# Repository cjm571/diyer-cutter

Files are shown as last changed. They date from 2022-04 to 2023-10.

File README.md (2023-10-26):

# Build Process

## Dev Container

### Windows 11

#### Prerequisites

* Ubuntu under WSL2
* Install and configure [USBIPD-WIN](https://learn.microsoft.com/en-us/windows/wsl/connect-usb#install-the-usbipd-win-project) in Ubuntu

#### Procedure

0. Connect BBC micro:bit to PC via USB
1. Run `tools/setup.ps1` to attach the micro:bit to WSL (see [this](https://github.com/dorssel/usbipd-win/wiki/WSL-support) if error occurs)
2. Execute `Dev Containers: Reopen in Container`
3. Open a terminal in the container and execute `cargo run`

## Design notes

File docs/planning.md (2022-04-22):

# Requirements
## Hardware
* The device shall be able to feed small-gauge wire to a cutting head.
* The device shall have a safety covering over the cutting head.
* The device shall be able to cut small-gauge wire.
* The device shall be able to cut small-gauge wire with an accuracy of ±1/16in
* The device shall have a single power on/off switch.
* The device shall display information and user prompts on a 16x2 LCD.
* The device shall accept user input from a 3x4 matrix keypad.
* The device shall drop cut wire into a receptacle.
* The device shall use a BBC micro:bit V2 as a system controller.
* The device shall enter a safe "fail state" if any errors are encountered.

## Software
* The software shall allow the user to select the desired size of cut wire.
* The software shall allow the user to select the number of wires to cut.
* The software shall be able to detect when a spool of wire has run out.

# Architecture
## State Machine
The micro:bit must maintain a set of states and transitions in order to provide a straightforward experience.

## Initialization
Upon receiving power, the peripheral devices attached to the micro:bit must be initialized (and optionally tested). This module will be responsible for performing these initialization sequences.

## Input Parsing
Inputs from peripheral devices must be received and parsed in order to determine the status of the system and perform to user specification.

## Motor Driver(s)
The motor(s) must be driven to user specification.

# Design
## Statechart
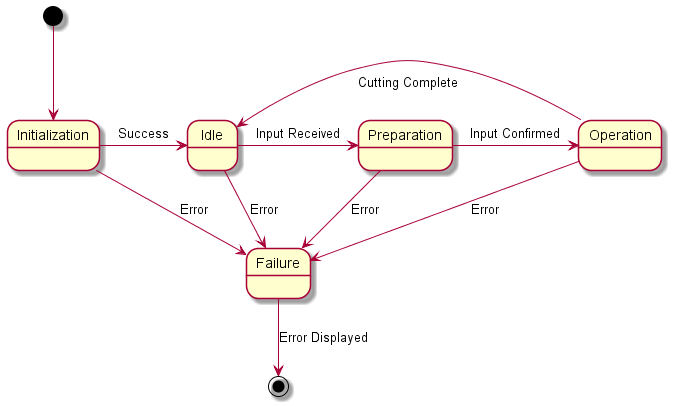
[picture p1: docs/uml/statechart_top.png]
Statechart


## Initialization
Upon power-up, the micro:bit will take the following sequence of actions:

1. Verify communications with LCD
2. Verify communications with keypad
3. Verify communications with motor(s) 
4. Enter Idle state

## Idle
A largely quiescent state where the micro:bit will sit idle until the user begins providing input via the keypad.

## Preparation
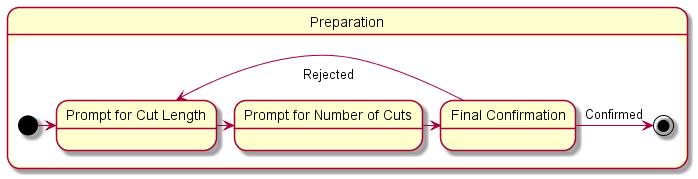
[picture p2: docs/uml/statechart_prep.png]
Statechart

This is the input-collection state. A series of prompts will be presented to the user on the LCD to determine the parameters of the cuts that should be made. The user will respond to the prompt and press "`#`" to confirm the response; "`*`" can be used as a backspace button. The prompts will be:

1. Cut length
```
0123456789012345
CUT LENGTH (in):
-> _
```
2. Number of cuts
```
0123456789012345
NUMBER OF CUTS:
-> _
```
3. Final confirmation
```
0123456789012345
XXin x YYYY
OK? (#=Y, *=N) _
```

If the user chooses "`*`" for "No" at the final prompt, the micro:bit will return to the first prompt. If the inputs are confirmed, the micro:bit will progress to the Operation stage.

## Operation
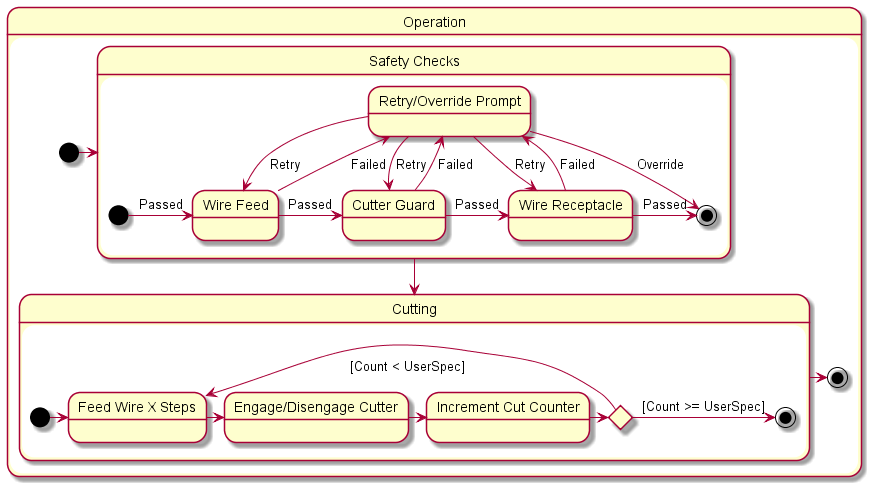
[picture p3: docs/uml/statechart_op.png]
Statechart

This is the cutting stage. Before cutting can begin, safety sensors are checked to ensure that the system is ready for safe operation. If any safety sensors are not in the right state, the micro:bit will prompt the user to check the associated safety device. The user may enter an override code to bypass the sensors in the event of an undetected error preventing the sensor from reporting correctly.

Safety checks include:

* Wire is properly fed
* Cutter guard is in place
* Cut wire receptacle is in place

Once safety checks have passed (or been overridden) the micro:bit will perform the following sequence of actions

1. Command feed stepper motor to advance the appropriate number of steps to reach the user-specified cut length.
2. Command cutter servo motor to engage the cutting head for one cycle
3. Increment cut counter
4. Repeat steps 1-3 until user-specified cut count is reached

Upon successful completion of all cuts, the micro:bit will return the system to the Idle state, where the user may begin the process again with more wire.

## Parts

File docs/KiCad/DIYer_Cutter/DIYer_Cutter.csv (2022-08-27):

Source: | D:\Documents\KiCad\6.0\projects\DIYer_Cutter\DIYer_Cutter.kicad_sch
Date: | 6/24/2022 9:31:56 PM
Tool: | Eeschema (6.0.5)
Generator: | C:\Program Files\KiCad\6.0\bin\scripting\plugins/bom_csv_grouped_by_value.py
Component Count: | 74
Individual Components:
Item | Qty | Reference(s) | Value | LibPart | Footprint | Datasheet
 |  | DS1 | WC1602A | Display_Character:WC1602A | Display:WC1602A | http://www.wincomlcd.com/pdf/WC1602A-SFYLYHTC06.pdf
 |  | M1 | Stepper_Motor_bipolar | Motor:Stepper_Motor_bipolar | Connector_PinHeader_2.54mm:PinHeader_1x04_P2.54mm_Vertical | http://www.infineon.com/dgdl/Application-Note-TLE8110EE_driving_UniPolarStepperMotor_V1.1.pdf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
 |  | M2 | Motor_Servo | Motor:Motor_Servo | Connector_PinHeader_2.54mm:PinHeader_1x03_P2.54mm_Horizontal | http://forums.parallax.com/uploads/attachments/46831/74481.png
 |  | R1 | R_Small_US | Device:R_Small_US |  | ~
 |  | R2 | R_Small_US | Device:R_Small_US |  | ~
 |  | R3 | R_Small_US | Device:R_Small_US |  | ~
 |  | R4 | R_Small_US | Device:R_Small_US |  | ~
 |  | R5 | R_Small_US | Device:R_Small_US |  | ~
 |  | R6 | R_Small_US | Device:R_Small_US |  | ~
 |  | R7 | R_Small_US | Device:R_Small_US |  | ~
 |  | R8 | R_Small_US | Device:R_Small_US |  | ~
 |  | R9 | R_Small_US | Device:R_Small_US |  | ~
 |  | R10 | R_Small_US | Device:R_Small_US |  | ~
 |  | R11 | R_Small_US | Device:R_Small_US |  | ~
 |  | R12 | R_Small_US | Device:R_Small_US |  | ~
 |  | R13 | R_Small_US | Device:R_Small_US |  | ~
 |  | R14 | R_Small_US | Device:R_Small_US |  | ~
 |  | R15 | R_Small_US | Device:R_Small_US |  | ~
 |  | R16 | R_Small_US | Device:R_Small_US |  | ~
 |  | R17 | R_Small_US | Device:R_Small_US |  | ~
 |  | R18 | R_Small_US | Device:R_Small_US |  | ~
 |  | R19 | R_Small_US | Device:R_Small_US |  | ~
 |  | R20 | R_Small_US | Device:R_Small_US |  | ~
 |  | R21 | R_Small_US | Device:R_Small_US |  | ~
 |  | R22 | R_Small_US | Device:R_Small_US |  | ~
 |  | R23 | R_Small_US | Device:R_Small_US |  | ~
 |  | R24 | R_Small_US | Device:R_Small_US |  | ~
 |  | R25 | R_Small_US | Device:R_Small_US |  | ~
 |  | R26 | R_Small_US | Device:R_Small_US |  | ~
 |  | R27 | R_Small_US | Device:R_Small_US |  | ~
 |  | R28 | R_Small_US | Device:R_Small_US |  | ~
 |  | R29 | R_Small_US | Device:R_Small_US |  | ~
 |  | R30 | R_Small_US | Device:R_Small_US |  | ~
 |  | R31 | R_Small_US | Device:R_Small_US |  | ~
 |  | R32 | R_Small_US | Device:R_Small_US |  | ~
 |  | R33 | R_Small_US | Device:R_Small_US |  | ~
 |  | R34 | R_Small_US | Device:R_Small_US |  | ~
 |  | R35 | R_Small_US | Device:R_Small_US |  | ~
 |  | R36 | R_Small_US | Device:R_Small_US |  | ~
 |  | R37 | R_Small_US | Device:R_Small_US |  | ~
 |  | R38 | R_Small_US | Device:R_Small_US |  | ~
 |  | R39 | R_Small_US | Device:R_Small_US |  | ~
 |  | R40 | R_Small_US | Device:R_Small_US |  | ~
 |  | R41 | R_Small_US | Device:R_Small_US |  | ~
 |  | R42 | R_Small_US | Device:R_Small_US |  | ~
 |  | R43 | R_Small_US | Device:R_Small_US |  | ~
 |  | R44 | R_Small_US | Device:R_Small_US |  | ~
 |  | R45 | R_Small_US | Device:R_Small_US |  | ~
 |  | R46 | R_Small_US | Device:R_Small_US |  | ~
 |  | R47 | R_Small_US | Device:R_Small_US |  | ~
 |  | R48 | R_Small_US | Device:R_Small_US |  | ~
 |  | R49 | R_Small_US | Device:R_Small_US |  | ~
 |  | R50 | R_Small_US | Device:R_Small_US |  | ~
 |  | R51 | R_Small_US | Device:R_Small_US |  | ~
 |  | R52 | R_Small_US | Device:R_Small_US |  | ~
 |  | R53 | R_Small_US | Device:R_Small_US |  | ~
 |  | R54 | R_Small_US | Device:R_Small_US |  | ~
 |  | R55 | R_Small_US | Device:R_Small_US |  | ~
 |  | R56 | R_Small_US | Device:R_Small_US |  | ~
 |  | R57 | R_Small_US | Device:R_Small_US |  | ~
 |  | R58 | R_Small_US | Device:R_Small_US |  | ~
 |  | R59 | R_Small_US | Device:R_Small_US |  | ~
 |  | R60 | R_Small_US | Device:R_Small_US |  | ~
 |  | R61 | R_Small_US | Device:R_Small_US |  | ~
 |  | R62 | R_Small_US | Device:R_Small_US |  | ~
 |  | SW1 | SW_Push | Switch:SW_Push |  | ~
 |  | U1 | micro:bit | DIYer_Cutter:BBC_micro{colon}bit_Breakout_Board
 |  | U2 | MCP23008-xP | Interface_Expansion:MCP23008-xP | Package_DIP:DIP-18_W7.62mm | http://ww1.microchip.com/downloads/en/DeviceDoc/MCP23008-MCP23S08-Data-Sheet-20001919F.pdf
 |  | U3 | MCP23008-xP | Interface_Expansion:MCP23008-xP | Package_DIP:DIP-18_W7.62mm | http://ww1.microchip.com/downloads/en/DeviceDoc/MCP23008-MCP23S08-Data-Sheet-20001919F.pdf
 |  | U4 | keypad_3x4_matrix | DIYer_Cutter:keypad_3x4_matrix
 |  | U5 | MCP23008-xP | Interface_Expansion:MCP23008-xP | Package_DIP:DIP-18_W7.62mm | http://ww1.microchip.com/downloads/en/DeviceDoc/MCP23008-MCP23S08-Data-Sheet-20001919F.pdf
 |  | U6 | easy_stepper_driver | DIYer_Cutter:easy_stepper_driver
 |  | U7 | 74HCT125 | DIYer_Cutter:74HCT125 |  | http://www.ti.com/lit/ds/symlink/sn74hct125.pdf
 |  | U8 | 74HC245 | 74xx:74HC245 | Package_DIP:DIP-20_W7.62mm | http://www.ti.com/lit/gpn/sn74HC245
Collated Components:
Item | Qty | Reference(s) | Value | LibPart | Footprint | Datasheet
1 | 1 | DS1 | WC1602A | Display_Character:WC1602A | Display:WC1602A | http://www.wincomlcd.com/pdf/WC1602A-SFYLYHTC06.pdf
2 | 1 | M1 | Stepper_Motor_bipolar | Motor:Stepper_Motor_bipolar | Connector_PinHeader_2.54mm:PinHeader_1x04_P2.54mm_Vertical | http://www.infineon.com/dgdl/Application-Note-TLE8110EE_driving_UniPolarStepperMotor_V1.1.pdf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
3 | 1 | M2 | Motor_Servo | Motor:Motor_Servo | Connector_PinHeader_2.54mm:PinHeader_1x03_P2.54mm_Horizontal | http://forums.parallax.com/uploads/attachments/46831/74481.png
4 | 62 | R1, R2, R3, R4, R5, R6, R7, R8, R9, R10, R11, R12, R13, R14, R15, R16, R17, R18, R19, R20, R21, R22, R23, R24, R25, R26, R27, R28, R29, R30, R31, R32, R33, R34, R35, R36, R37, R38, R39, R40, R41, R42, R43, R44, R45, R46, R47, R48, R49, R50, R51, R52, R53, R54, R55, R56, R57, R58, R59, R60, R61, R62 | R_Small_US | Device:R_Small_US |  | ~
5 | 1 | SW1 | SW_Push | Switch:SW_Push |  | ~
6 | 1 | U1 | micro:bit | DIYer_Cutter:BBC_micro{colon}bit_Breakout_Board
7 | 3 | U2, U3, U5 | MCP23008-xP | Interface_Expansion:MCP23008-xP | Package_DIP:DIP-18_W7.62mm | http://ww1.microchip.com/downloads/en/DeviceDoc/MCP23008-MCP23S08-Data-Sheet-20001919F.pdf
8 | 1 | U4 | keypad_3x4_matrix | DIYer_Cutter:keypad_3x4_matrix
9 | 1 | U6 | easy_stepper_driver | DIYer_Cutter:easy_stepper_driver
10 | 1 | U7 | 74HCT125 | DIYer_Cutter:74HCT125 |  | http://www.ti.com/lit/ds/symlink/sn74hct125.pdf
11 | 1 | U8 | 74HC245 | 74xx:74HC245 | Package_DIP:DIP-20_W7.62mm | http://www.ti.com/lit/gpn/sn74HC245

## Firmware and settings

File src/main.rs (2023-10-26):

/*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
\* * * * * * * * * * * * * * * * * * * * * * * * * * * * * * * * * * * * * * */

#![no_main]
#![no_std]

use core::cell::RefCell;

use cortex_m::{
    interrupt::{self as cortex_interrupt, Mutex},
    peripheral::NVIC,
};

use microbit::{
    hal::{gpio::Level, prelude::*, timer, twim, Timer, Twim},
    pac::{interrupt, Interrupt, PWM0, TIMER0, TIMER1, TWIM0},
    Board,
};

mod i2c;
use crate::i2c::{
    keypad::{self, Key},
    lcd1602,
};

mod servo;
use servo::Servo;

///////////////////////////////////////////////////////////////////////////////
//  Named Constants
///////////////////////////////////////////////////////////////////////////////

const ONE_SECOND_IN_MHZ: u32 = 1000000;
const GREETING_DUR_IN_MS: u32 = 2500;

// Cap input to 5 digits for ease of implementation
const MAX_INPUT_CHARS: usize = 5;

const CUT_CYCLE_TIME_MS: u32 = 1500;
const WIRE_FEED_TIME_MS: u32 = 3000;

///////////////////////////////////////////////////////////////////////////////
//  Shared Peripheral Handles
///////////////////////////////////////////////////////////////////////////////

static TIMER0_HANDLE: Mutex<RefCell<Option<Timer<TIMER0>>>> = Mutex::new(RefCell::new(None));
static TIMER1_HANDLE: Mutex<RefCell<Option<Timer<TIMER1>>>> = Mutex::new(RefCell::new(None));
static I2C0_HANDLE: Mutex<RefCell<Option<Twim<TWIM0>>>> = Mutex::new(RefCell::new(None));
static CUTTER_HANDLE: Mutex<RefCell<Option<Servo<PWM0>>>> = Mutex::new(RefCell::new(None));

///////////////////////////////////////////////////////////////////////////////
//  Tasks
///////////////////////////////////////////////////////////////////////////////

#[cortex_m_rt::entry]
fn main() -> ! {
    defmt::println!("Hello, world!");

    init();

    defmt::println!("Initialization Complete!");

    idle();
}

fn init() {
    // Take ownership of the full board
    let board = Board::take().unwrap();

    // Hold various chips in reset/output-disabled
    let i2c_reset_pin = board.pins.p1_02.into_push_pull_output(Level::Low); // P16
    let mut lcd_lvshift_oe_pin = board.pins.p0_12.into_push_pull_output(Level::High); // P12

    // Instantiate a timer
    let timer0 = init_1s_timer(board.TIMER0);

    // Initialize a 1-second timer
    let timer1 = init_1s_timer(board.TIMER1);
    cortex_interrupt::free(|cs| TIMER1_HANDLE.borrow(cs).replace(Some(timer1)));

    // Initialize the TWIM0 (I2C) controller
    let mut i2c0 = i2c::init(
        board.TWIM0,
        board.i2c_external,
        &mut i2c_reset_pin.degrade(),
    );

    // Initialize LCD Display and display greeting
    defmt::println!("Enabling power to LCD Display...");
    lcd1602::power_on(&mut i2c0);

    defmt::println!("Enabling output on LCD Level Shifter...");
    lcd_lvshift_oe_pin.set_low().unwrap();

    defmt::println!("Initializing LCD Display...");
    cortex_interrupt::free(|cs| {
        let mut local_timer1_handle_ref = TIMER1_HANDLE.borrow(cs).borrow_mut();
        let local_timer1_handle = local_timer1_handle_ref.as_mut().unwrap();
        lcd1602::init(local_timer1_handle, &mut i2c0);
    });

    defmt::println!("Initializing 3x4 Matrix Keypad...");
    keypad::init(&mut i2c0);

    defmt::println!("Initializing Cutter Servo...");
    let pwm_output_pin = board.pins.p0_09.into_push_pull_output(Level::Low).degrade();
    let cutter = Servo::new(board.PWM0, microbit::hal::pwm::Channel::C0, pwm_output_pin);

    // Store the peripheral handles in RefCells, so interrupts and main thread can use them
    cortex_interrupt::free(|cs| TIMER0_HANDLE.borrow(cs).replace(Some(timer0)));
    cortex_interrupt::free(|cs| I2C0_HANDLE.borrow(cs).replace(Some(i2c0)));
    cortex_interrupt::free(|cs| CUTTER_HANDLE.borrow(cs).replace(Some(cutter)));
}

fn idle() -> ! {
    cortex_interrupt::free(|cs| {
        // Capture shared peripheral handles locally
        let mut local_timer0_handle_ref = TIMER0_HANDLE.borrow(cs).borrow_mut();
        let timer0 = local_timer0_handle_ref.as_mut().unwrap();
        let mut local_i2c0_handle_ref = I2C0_HANDLE.borrow(cs).borrow_mut();
        let i2c0 = local_i2c0_handle_ref.as_mut().unwrap();
        let mut local_cutter_handle_ref = CUTTER_HANDLE.borrow(cs).borrow_mut();
        let cutter = local_cutter_handle_ref.as_mut().unwrap();

        // Display greeting
        lcd1602::display_greeting(timer0, i2c0);
        timer0.delay_ms(GREETING_DUR_IN_MS);

        // Input Loop
        let mut cut_length;
        let mut num_cuts;
        loop {
            // Prompt user for Cut Length
            defmt::println!("Prompting user for Cut Length...");
            cut_length = get_user_parameter("CUT LENGTH (in):\n-> ", timer0, i2c0);
            defmt::println!("User accepted Cut Length of {}", cut_length);

            // Prompt user for Number of Cuts
            defmt::println!("Prompting user for Number of Cuts...");
            num_cuts = get_user_parameter("NUMBER OF CUTS:\n-> ", timer0, i2c0);
            defmt::println!("User accepted Number of Cuts of {}", num_cuts);

            // Present final confirmation
            defmt::println!("Presenting final confirmation to user...");
            if !final_confirmation(cut_length, num_cuts, timer0, i2c0) {
                // User rejected confirmation, return to top of input loop
                defmt::println!("User rejected confirmation");
                continue;
            } else {
                // User accepted confirmation, break out of input loop
                defmt::println!("User accepted confirmation");
                break;
            }
        }

        // Cutting Loop
        lcd1602::clear_display(timer0, i2c0);
        lcd1602::write_string("Cutting...\n00000 / ", timer0, i2c0);
        lcd1602::write_u32(num_cuts, timer0, i2c0);
        lcd1602::shift_cursor(lcd1602::Direction::Left, 8, timer0, i2c0);
        for i in 1..=num_cuts {
            // Update LCD
            lcd1602::backspace(5, timer0, i2c0);
            lcd1602::write_u32(i, timer0, i2c0);

            // Perform a single cut
            cutter.set_duty(12.0);
            timer0.delay_ms(CUT_CYCLE_TIME_MS);
            cutter.set_duty(3.0);

            // Allow time for wire feed
            timer0.delay_ms(WIRE_FEED_TIME_MS);
        }

        lcd1602::clear_display(timer0, i2c0);
        lcd1602::write_string("Finished Cutting\nWoohoo! <3", timer0, i2c0);
    });

    defmt::println!("Entering Idle loop");
    loop {
        cortex_interrupt::free(|cs| {
            // Capture shared peripheral handles locally
            let mut local_timer0_handle_ref = TIMER0_HANDLE.borrow(cs).borrow_mut();
            let timer0 = local_timer0_handle_ref.as_mut().unwrap();
            timer0.delay_ms(500_u32);
        });
    }
}

///////////////////////////////////////////////////////////////////////////////
//  Helper Functions
///////////////////////////////////////////////////////////////////////////////

fn init_1s_timer<T: timer::Instance>(instance: T) -> Timer<T> {
    // Create the Timer object
    let mut timer_device = Timer::new(instance);

    // Stop and clear the timer before configuring it
    timer_device.task_stop().write(|w| w.tasks_stop().trigger());
    timer_device
        .task_clear()
        .write(|w| w.tasks_clear().trigger());

    // [2022-05-15] Don't need to set prescaler or bit mode because microbit crate
    // currently hardcodes these to 1MHz and 32bit mode

    // Enable and unmask the interrupt
    timer_device.enable_interrupt();
    unsafe {
        NVIC::unmask(Interrupt::TIMER1);
    }

    // [2022-05-15] microbit crate currently does not expose the SHORTS register space
    // Cannot configure timer to auto-reset on reaching the specified tick count

    // Start the timer
    timer_device.start(ONE_SECOND_IN_MHZ);

    timer_device
}

fn get_user_parameter<T: timer::Instance, U: twim::Instance>(
    prompt: &str,
    timer: &mut Timer<T>,
    i2c: &mut Twim<U>,
) -> u32 {
    lcd1602::clear_display(timer, i2c);
    lcd1602::write_string(prompt, timer, i2c);

    let mut user_input: [&str; 12] = [""; 12];
    let mut user_input_idx = 0;
    loop {
        if let Some(pressed_key) = keypad::scan(timer, i2c) {
            // Check for '#', which will parse and accept the input
            if pressed_key == Key::Pound {
                let mut parsed_input = 0;
                for (order_of_magnitude, parsed_value) in user_input
                    .iter()
                    .rev()
                    .flat_map(|v| v.parse::<u32>())
                    .enumerate()
                {
                    parsed_input += parsed_value * u32::pow(10, order_of_magnitude as u32);
                }

                return parsed_input;
            }
            // Check for '*', which acts as a backspace key
            if pressed_key == Key::Star {
                //OPT: Beep if input is empty?
                // Don't allow backspace if input is empty
                if user_input_idx > 0 {
                    lcd1602::backspace(1, timer, i2c);
                    user_input_idx -= 1;
                    user_input[user_input_idx] = "";
                }

                continue;
            }

            //OPT: Beep if input is full?
            // If not at max length, write the key to the LCD and record it in the input array
            if user_input_idx < MAX_INPUT_CHARS {
                lcd1602::write_string(pressed_key.into(), timer, i2c);
                user_input[user_input_idx] = pressed_key.into();
                user_input_idx += 1;
            }
        } else {
            continue;
        }
    }
}

fn final_confirmation<T: timer::Instance, U: twim::Instance>(
    cut_length: u32,
    num_cuts: u32,
    timer: &mut Timer<T>,
    i2c: &mut Twim<U>,
) -> bool {
    lcd1602::clear_display(timer, i2c);
    lcd1602::write_u32(cut_length, timer, i2c);
    lcd1602::write_string("in x ", timer, i2c);
    lcd1602::write_u32(num_cuts, timer, i2c);
    lcd1602::write_string("\nOK? (#=Y, *=N) ", timer, i2c);

    loop {
        if let Some(pressed_key) = keypad::scan(timer, i2c) {
            if pressed_key == Key::Pound {
                // User accepted confirmation
                return true;
            } else if pressed_key == Key::Star {
                // User rejected confirmation
                return false;
            } else {
                continue;
            }
        }
    }
}

///////////////////////////////////////////////////////////////////////////////
//  Interrupt Handlers
///////////////////////////////////////////////////////////////////////////////

#[interrupt]
fn TIMER1() {
    // Clear the timer interrupt flag && restart 1s timer
    cortex_interrupt::free(|cs| {
        let mut local_timer1_handle_ref = TIMER1_HANDLE.borrow(cs).borrow_mut();
        let local_timer1_handle = local_timer1_handle_ref.as_mut().unwrap();
        local_timer1_handle
            .event_compare_cc0()
            .write(|w| w.events_compare().not_generated());

        local_timer1_handle.start(ONE_SECOND_IN_MHZ);
    });
}

///////////////////////////////////////////////////////////////////////////////
//  Embedded Boilerplate
///////////////////////////////////////////////////////////////////////////////

use cortex_m_semihosting::debug;

use defmt_rtt as _; // global logger

use microbit as _; // memory layout

use panic_probe as _;

// same panicking *behavior* as `panic-probe` but doesn't print a panic message
// this prevents the panic message being printed *twice* when `defmt::panic` is invoked
#[defmt::panic_handler]
fn panic() -> ! {
    cortex_m::asm::udf()
}

/// Terminates the application and makes a semihosting-capable debug tool exit
/// with status code 0.
pub fn exit() -> ! {
    loop {
        debug::exit(debug::EXIT_SUCCESS);
    }
}

/// Hardfault handler.
///
/// Terminates the application and makes a semihosting-capable debug tool exit
/// with an error. This seems better than the default, which is to spin in a
/// loop.
#[cortex_m_rt::exception]
unsafe fn HardFault(_frame: &cortex_m_rt::ExceptionFrame) -> ! {
    loop {
        debug::exit(debug::EXIT_FAILURE);
    }
}

// defmt-test 0.3.0 has the limitation that this `#[tests]` attribute can only be used
// once within a crate. the module can be in any file but there can only be at most
// one `#[tests]` module in this library crate
#[cfg(test)]
#[defmt_test::tests]
mod unit_tests {
    use defmt::assert;

    #[test]
    fn it_works() {
        assert!(true)
    }
}

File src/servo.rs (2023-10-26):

/*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
\* * * * * * * * * * * * * * * * * * * * * * * * * * * * * * * * * * * * * * */

use core::fmt::Debug;
use microbit::hal::{
    gpio::{Output, Pin, PushPull},
    pwm,
};

///////////////////////////////////////////////////////////////////////////////
//  Named Constants
///////////////////////////////////////////////////////////////////////////////

const FIFTY_HZ_IN_500KHZ_TICKS: u16 = 10000;
const PWM_ENABLE: u32 = 1;
const TRIGGER_TASK: u32 = 1;
const INFINITY_SAFE_LOOP_CNT: u32 = 2;

const DECODER_CMP_VALUE_MASK: u16 = 0x7FFF;

///////////////////////////////////////////////////////////////////////////////
//  Data Structures
///////////////////////////////////////////////////////////////////////////////

pub struct Servo<T: pwm::Instance> {
    pwm_inst: T,
    _channel: pwm::Channel,
    _output_pin: Pin<Output<PushPull>>,
    common_duty: [u16; 2],
}

///////////////////////////////////////////////////////////////////////////////
//  Object Implementations
///////////////////////////////////////////////////////////////////////////////

impl<T: pwm::Instance> Servo<T> {
    pub fn new(pwm_inst: T, channel: pwm::Channel, output_pin: Pin<Output<PushPull>>) -> Self {
        // Before configuring, trigger TASKS_STOP to ensure a stable reset state
        pwm_inst
            .tasks_stop
            .write(|w| unsafe { w.bits(TRIGGER_TASK) });

        // Set the output pin
        pwm_inst.psel.out[0].write(|w| unsafe { w.bits(output_pin.psel_bits()) });

        // Enable the PWM Generator
        pwm_inst.enable.write(|w| unsafe { w.bits(PWM_ENABLE) });

        // Set the frequency to 50Hz via PRESCALER, COUNTERTOP register
        pwm_inst.prescaler.write(|w| w.prescaler().div_32()); // Divide clock down to 500kHz
        pwm_inst
            .countertop
            .write(|w| unsafe { w.countertop().bits(FIFTY_HZ_IN_500KHZ_TICKS) });

        // Set the duty cycle to 0 (common to all channels due to default DECODER config)
        let common_duty = [0, 0];
        pwm_inst
            .seq0
            .ptr
            .write(|w| unsafe { w.ptr().bits(common_duty.as_ptr() as u32) });
        pwm_inst.seq0.cnt.write(|w| unsafe { w.bits(1) });
        pwm_inst.seq0.refresh.write(|w| unsafe { w.bits(0) });

        // Configure PWM to loop infinitely on common duty cycle sequence by setting loop count > 1
        // and enabling shortcut that will link the LOOPSDONE even and SEQSTART[0]
        pwm_inst
            .loop_
            .write(|w| unsafe { w.bits(INFINITY_SAFE_LOOP_CNT) });
        pwm_inst.shorts.write(|w| w.loopsdone_seqstart0().enabled());

        // Note: The following registers are left untouched as their reset values are already the desired values:
        // MODE, DECODER, SEQ[0].ENDDELAY, SEQ[1].*

        Self {
            pwm_inst,
            _channel: channel,
            _output_pin: output_pin,
            common_duty,
        }
    }

    pub fn set_duty(&mut self, duty: f32) {
        // Set the new duty cycle
        self.common_duty = [
            ((FIFTY_HZ_IN_500KHZ_TICKS as f32 / 100.0) * duty) as u16 | 1 << 15,
            0,
        ];
        self.pwm_inst
            .seq0
            .ptr
            .write(|w| unsafe { w.ptr().bits(self.common_duty.as_ptr() as u32) });

        // Start the sequence again
        self.pwm_inst.tasks_seqstart[0].write(|w| unsafe { w.bits(TRIGGER_TASK) });
    }
}

impl<T: pwm::Instance> Debug for Servo<T> {
    fn fmt(&self, f: &mut core::fmt::Formatter<'_>) -> core::fmt::Result {
        // Gather register values
        let shorts = self.pwm_inst.shorts.read().bits();
        let enable = self.pwm_inst.enable.read().bits();
        let mode = self.pwm_inst.mode.read().bits();
        let countertop = self.pwm_inst.countertop.read().bits();
        let prescaler = self.pwm_inst.prescaler.read().bits();
        let decoder = self.pwm_inst.decoder.read().bits();
        let loop_ = self.pwm_inst.loop_.read().bits();
        let seq0_ptr = self.pwm_inst.seq0.ptr.read().bits();
        let seq0_cnt = self.pwm_inst.seq0.cnt.read().bits();
        let seq1_ptr = self.pwm_inst.seq1.ptr.read().bits();
        let seq1_cnt = self.pwm_inst.seq1.cnt.read().bits();
        let psel = self.pwm_inst.psel.out[0].read().bits();

        // UNSAFELY retrieve seq values
        let seq0_val = unsafe { *(seq0_ptr as *const i32) };
        let seq1_val = unsafe { *(seq1_ptr as *const i32) };

        f.write_fmt(format_args!("Servo Register Map:\n"))?;
        f.write_fmt(format_args!("  SHORTS:         {:0>8b}\n", shorts))?;
        f.write_fmt(format_args!("  ENABLE:         {:0>8b}\n", enable))?;
        f.write_fmt(format_args!("  MODE:           {:0>8b}\n", mode))?;
        f.write_fmt(format_args!(
            "  COUNTERTOP:     {:0>8b} ({})\n",
            countertop, countertop
        ))?;
        f.write_fmt(format_args!(
            "  PRESCALER:      {:0>8b} ({})\n",
            prescaler, prescaler
        ))?;
        f.write_fmt(format_args!("  DECODER:        {:0>8b}\n", decoder))?;
        f.write_fmt(format_args!(
            "  LOOP:           {:0>8b} ({})\n",
            loop_, loop_
        ))?;
        f.write_fmt(format_args!(
            "  SEQ[0]PTR, CNT: {:0>8x}, {:0>8b} ({})\n",
            seq0_ptr, seq0_cnt, seq0_cnt
        ))?;
        f.write_fmt(format_args!(
            "  SEQ[0] Value:   {:0>16b} ({})\n",
            seq0_val,
            seq0_val & DECODER_CMP_VALUE_MASK as i32
        ))?;
        f.write_fmt(format_args!(
            "  SEQ[1]PTR, CNT: {:0>8x}, {:0>8b} ({})\n",
            seq1_ptr, seq1_cnt, seq1_cnt
        ))?;
        f.write_fmt(format_args!(
            "  SEQ[1] Value:   {:0>16b} ({})\n",
            seq1_val,
            seq1_val & DECODER_CMP_VALUE_MASK as i32
        ))?;
        f.write_fmt(format_args!("  PSEL.OUT[0]:    {:0>8b}\n", psel))?;

        Ok(())
    }
}

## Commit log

2022-05-03 String printing working!
2022-05-15 working timer interrupts!
2022-05-15 Working timer interrupts without raw pointers (aka "writing C in Rust")
2022-05-15 Working counter in interrupt handler
2022-06-13 Replaced P13 with P5 for LCD D5
    [main.rs]
2022-06-26 Implemented barebones allocator Updated memory.x to correctly reflect micro:bit hardware
    [lcd1602.rs, main.rs]
2022-07-17 Multiple timers working with RTIC
2022-08-05 Removed SWI0_EDU0 interrupt dispatcher to correct hang
    [main.rs]
2022-08-05 Created I2C Verification array
2022-08-06 Added P16 as global I2C reset pin, resets during init to avoid inconsistencies when not powering off between flashes
    [main.rs]
2022-08-06 Working I2C reads!
2022-08-06 Working I2C Writes!!!
2022-08-06 Added helper functions for timer, i2c device init
2022-08-06 Formatting fixes, removed microbit_allocator.rs
    [main.rs]
2022-08-07 Added i2c_periphs to repo
2022-08-20 Theoretically working LCD init based on i2c verf pins
2022-08-25 Working I2C to LCD! - Removed level shifter - Added transistor for controlling LCD power
2022-08-27 Added LCD power on/off via i2c
2022-08-27 Added kicad files to docs dir
    [DIYer_Cutter.csv, DIYer_Cutter.kicad_pcb, DIYer_Cutter.kicad_sch]
2022-09-03 Mostly hardware issue, but working I2C + Level Shifter LCD driving
    [main.rs]
2022-09-03 Blinking lights on keypad MCP23008 without affecting LCD! - Reorg of i2c_periphs in progress - created keypad.rs
2022-09-04 Successful I2C GPIO read from keypad MCP23008
2022-09-05 Working keypad reads over i2c!
2022-09-05 Cut length prompt added after greeting
2022-09-05 Fixed user input loop breaking on "#"
    [main.rs]
2022-09-12 Removed KiCad backups dir from repo, updated .gitignore
2022-09-12 Clippy fixes, cargo fmt
    [keypad.rs, lcd1602.rs, main.rs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]
2022-09-12 Updated schematic
    [DIYer_Cutter.kicad_sch]
2022-09-17 Potentially working PWM!
2022-09-17 Working servo control!
2023-10-14 Probably working devcontainers config
    [DIYer_Cutter.kicad_sch]
2023-10-22 Successfully migrated to 'standard' embedded Rust framework!

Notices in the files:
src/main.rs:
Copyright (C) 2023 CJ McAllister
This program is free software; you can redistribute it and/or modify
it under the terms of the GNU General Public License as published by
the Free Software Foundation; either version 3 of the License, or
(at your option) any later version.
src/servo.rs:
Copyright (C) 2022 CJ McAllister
